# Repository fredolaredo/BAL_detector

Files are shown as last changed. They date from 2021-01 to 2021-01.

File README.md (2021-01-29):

# BAL_detector

## objectif

recevoir une notification sur ouverture de la boite aux lettre qui se trouve en bas de l'immeuble

fixation par aimant (je ne voulais pas faire de trous dans la BAL et plus facile pour récupérer pour recharger la batterie

basse consommation pour tourner avec une batterie sur plusieurs mois 

## principe

1. ouverture de la porte de la BAL par capteur magnétique

2. envoi d'un packet lora contenant des données ambiantes et le voltage de la batterie

3. notification IFTTT sur message TTN

## composants

atmega328 package DIP28 en 3,3V / 8Mhz

LoRa 1276

DHT22 (pour le fun)

une baterie Lithium 3,7v 1000mAh

un contacteur par effet magnétique

quelques composants passifs : led , resistances, capa de découplage, un push button, ...

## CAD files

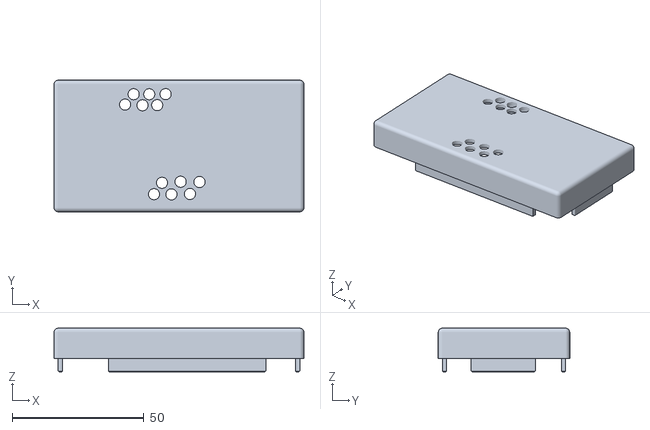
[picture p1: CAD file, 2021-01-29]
3D/BAL_haut.stl
95.0 x 50.0 x 16.6

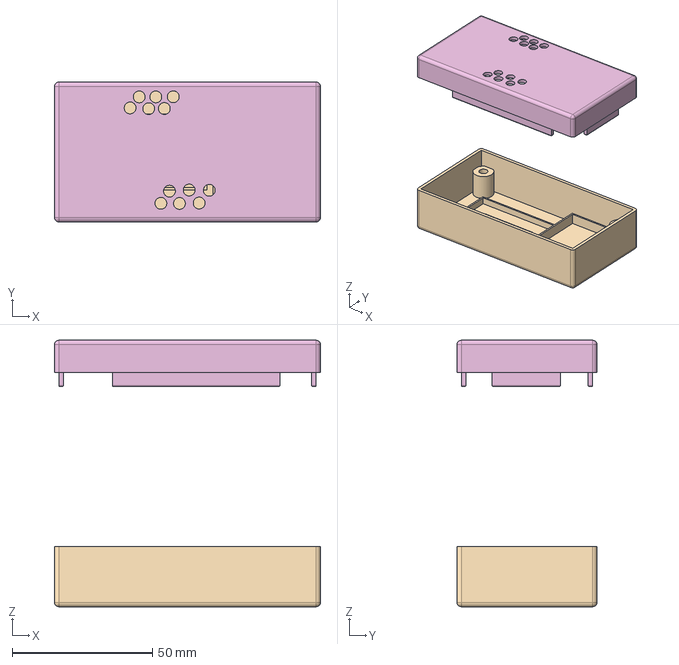
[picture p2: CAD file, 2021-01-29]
3D/boite.FCStd
95.0 x 50.0 x 95.2 mm
Bas
Couvercle

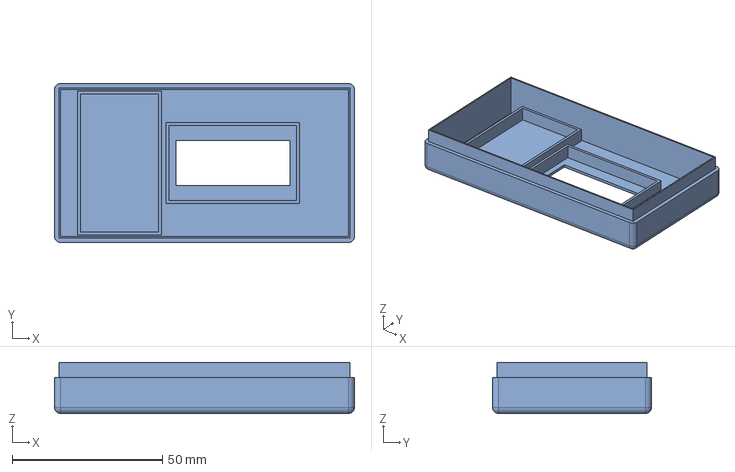
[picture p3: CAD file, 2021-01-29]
3D/coffre_91x47.FCStd
100.0 x 53.0 x 17.0 mm

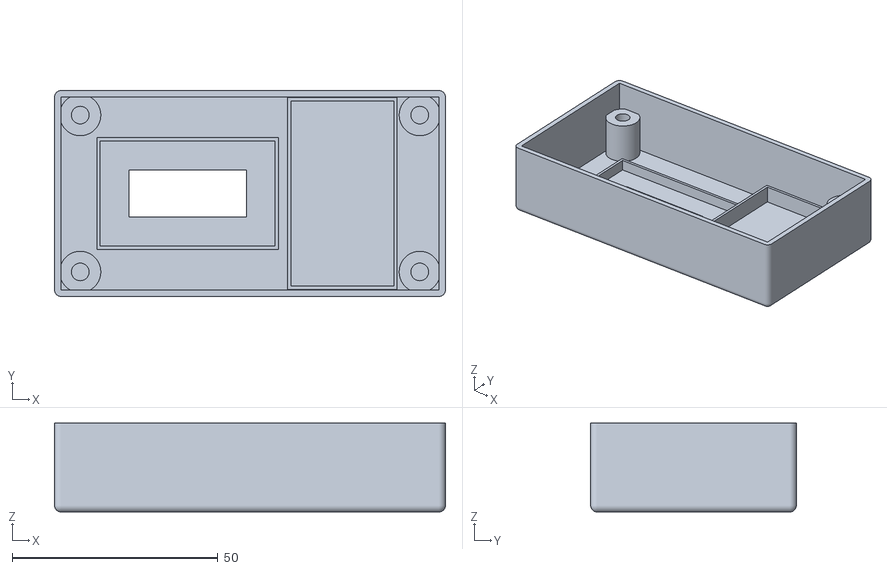
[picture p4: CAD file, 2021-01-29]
3D/BAL_bas.stl
95.0 x 50.0 x 21.6

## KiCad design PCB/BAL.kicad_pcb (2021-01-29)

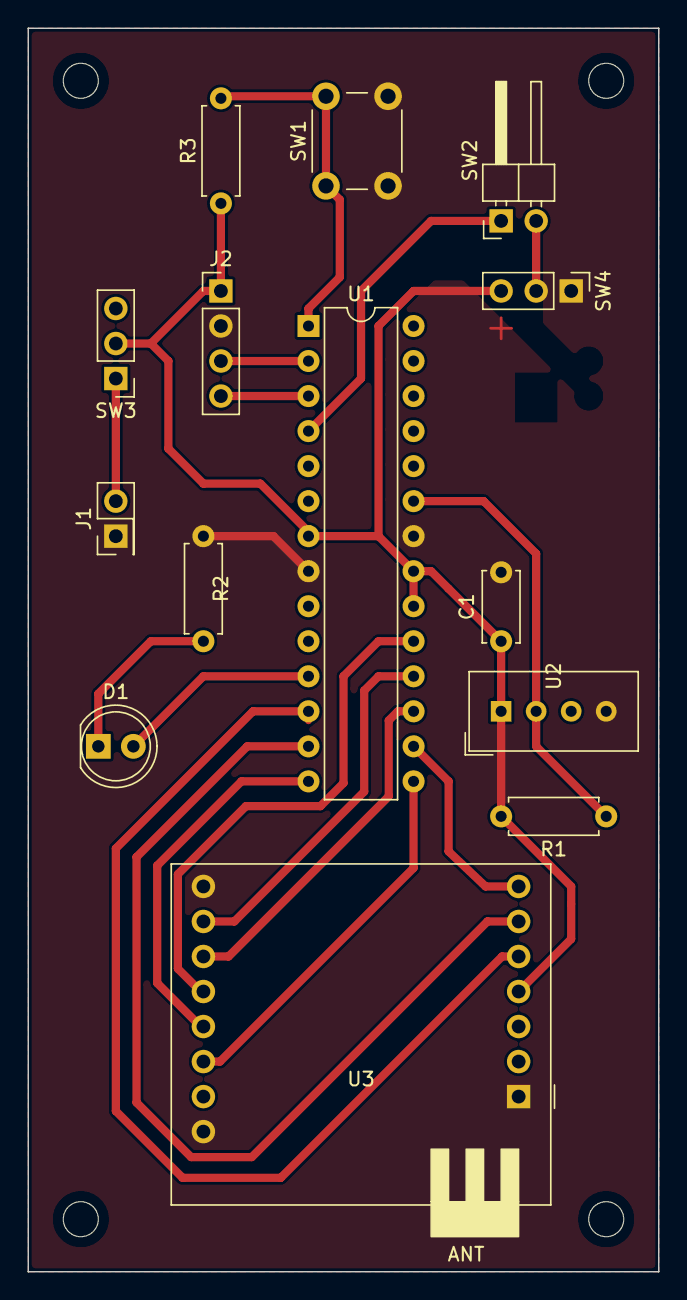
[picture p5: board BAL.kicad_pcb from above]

Board: 2 copper layers, 45.7 x 90.2 mm, 14 parts (0 on the bottom side), 19 nets.

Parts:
C1: 1nF; C_Disc_D5.0mm_W2.5mm_P5.00mm
D1: LED; LED_D5.0mm
J1: Battery; PinHeader_2x01_P2.54mm_Vertical
J2: UART; PinHeader_1x04_P2.54mm_Vertical
R1, R3: 10k; R_Axial_DIN0207_L6.3mm_D2.5mm_P7.62mm_Horizontal
R2: 180; R_Axial_DIN0207_L6.3mm_D2.5mm_P7.62mm_Horizontal
SW1: SW_Push; SW_PUSH_6mm
SW2: Detecteur; PinHeader_1x02_P2.54mm_Horizontal
SW3: SW_SPST; PinHeader_1x03_P2.54mm_Vertical
SW4: NO/NC; PinHeader_1x03_P2.54mm_Vertical
U1: ATmega328P-PU; DIP-28_W7.62mm
U2: DHT11; Aosong_DHT11_5.5x12.0_P2.54mm
U3: SX1276_package; SX1276_Package

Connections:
+3V3: C1.1, J2.1, R1.2, R3.1, SW3.2, SW4.3, U1.7, U1.20, U1.21, U2.1, U3.4
D0: U1.12, U3.5
D1: U1.13, U3.6
D2: U1.16, U3.7
DATA: R1.1, U1.23, U2.2
GND: C1.2, J1.1, J2.2, R2.1, SW1.2, SW4.1, U1.8, U1.22, U2.4, U3.1, U3.8, U3.15
MISO: U1.18, U3.14
MOSI: U1.17, U3.13
unnamed: D1.1, R2.2
unnamed: D1.2, U1.11
unnamed: J1.2, SW3.1
unnamed: R3.2, SW1.1, U1.1
unnamed: SW2.1, U1.4
unnamed: SW2.2, SW4.2
RST: U1.15, U3.10
RX: J2.4, U1.3
SCK: U1.19, U3.12
SS: U1.14, U3.11
TX: J2.3, U1.2

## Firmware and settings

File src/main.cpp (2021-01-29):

#include <Arduino.h>
#include "private.h"

#include <lmic.h>
#include <hal/hal.h>
#include <SPI.h>
#include "time.h"

#define CONTACT_PIN   2
#define LED_PIN       5
#define STANDARD_DIM  50

int nbLoop = 0;

enum STATE {
  INIT,
  SEND,
  WAIT_SEND,
  SLEEP,
  ERROR
};

volatile STATE state = INIT;

void dimLed(int msecs = 1000, int power = STANDARD_DIM, int num = 1) {
  #define pas 2
  for (int nb=0 ; nb < num ; nb++) {
    for (int j=0; j<power ; j+= pas ) {
      analogWrite(LED_PIN,j); 
      delay(msecs / 2 / (power / pas)); 
    }
    for (int j=power; j>0 ; j-= pas) {
      analogWrite(LED_PIN,j);  
      delay( msecs / 2 / (power / pas));
    }
    digitalWrite(LED_PIN,LOW);
  }
  
}


///////////////////////////////////////////////////////////////////
// DHT22
///////////////////////////////////////////////////////////////////
#include <Adafruit_Sensor.h>
#include <DHT.h>
#include <DHT_U.h>

#define DHTPIN     A0        // Digital pin connected to the DHT sensor 
#define DHTTYPE    DHT22     // DHT 22 (AM2302)

DHT_Unified dht(DHTPIN, 22);

uint32_t delayMS;
float temperature;
float humidity;

void initDHT() {
  Serial.println("DHT22 started");
  dht.begin();
}

void getTempHumid() {
  sensors_event_t event;

  dht.temperature().getEvent(&event);
  dht.humidity().getEvent(&event);
  
  dht.temperature().getEvent(&event);
  if (isnan(event.temperature)) {
    Serial.println(F("Error reading temperature!"));
  } else {
    Serial.print(F("Temperature: "));
    Serial.print(event.temperature);
    Serial.println(F("°C"));
    temperature = event.temperature;
  }
  dht.humidity().getEvent(&event);
  if (isnan(event.relative_humidity)) {
    Serial.println(F("Error reading humidity!"));
  } else {
    Serial.print(F("Humidity: "));
    Serial.print(event.relative_humidity);
    Serial.println(F("%"));
    humidity = event.relative_humidity;
  }
}

//////////////////////////////////////////////////////////////////
// SX1276
///////////////////////////////////////////////////////////////////

#define SX1276_NSS  8
#define SX1276_RST  9 
#define SX1276_DIO2 10
#define SX1276_MOSI 11
#define SX1276_MISO 12
#define SX1276_SCK  13
#define SX1276_DIO0 6
#define SX1276_DIO1 7

void opmode_str(){
  if (LMIC.opmode & OP_NONE) Serial.print(" OP_NONE");
  if (LMIC.opmode & OP_SCAN) Serial.print(" OP_SCAN");          // radio scan to find a beacon
  if (LMIC.opmode & OP_TRACK) Serial.print(" OP_TRACK");        // track my networks beacon (netid)
  if (LMIC.opmode & OP_JOINING) Serial.print(" OP_JOINING");    // device joining in progress (blocks other activities)
  if (LMIC.opmode & OP_TXDATA) Serial.print(" OP_TXDATA");      // TX user data (buffered in pendTxData)
  if (LMIC.opmode & OP_POLL) Serial.print(" OP_POLL");          // send empty UP frame to ACK confirmed DN/fetch more DN data
  if (LMIC.opmode & OP_REJOIN) Serial.print(" OP_REJOIN");      // occasionally send JOIN REQUEST
  if (LMIC.opmode & OP_SHUTDOWN) Serial.print(" OP_SHUTDOWN");  // prevent MAC from doing anything
  if (LMIC.opmode & OP_TXRXPEND) Serial.print(" OP_TXRXPEND");  // TX/RX transaction pending
  if (LMIC.opmode & OP_RNDTX) Serial.print(" OP_RNDTX");        // prevent TX lining up after a beacon
  if (LMIC.opmode & OP_PINGINI) Serial.print(" OP_PINGINI");    // pingable is initialized and scheduling active
  if (LMIC.opmode & OP_PINGABLE) Serial.print(" OP_PINGABLE");  // we're pingable
  if (LMIC.opmode & OP_NEXTCHNL) Serial.print(" OP_NEXTCHNL");  // find a new channel
  if (LMIC.opmode & OP_LINKDEAD) Serial.print(" OP_LINKDEAD");  // link was reported as dead
  if (LMIC.opmode & OP_TESTMODE) Serial.print(" OP_TESTMODE");  // developer test mode
}


#ifdef ABP
  uint8_t APPSKEY[16] = SECRET_APPKEY;  
  uint8_t NWKSKEY[16] = SECRET_NWKSKEY;   
  static const u4_t DEVADDR =  SECRET_DEVADDR; 
  void os_getArtEui (u1_t* buf) { }
  void os_getDevEui (u1_t* buf) { }
  void os_getDevKey (u1_t* buf) { }
#else
  static const u1_t PROGMEM APPEUI[8]= SECRET_APPEUI;
  void os_getArtEui (u1_t* buf) { memcpy_P(buf, APPEUI, 8);}
  static const u1_t PROGMEM DEVEUI[8]= SECRET_DEVEUI;
  void os_getDevEui (u1_t* buf) { memcpy_P(buf, DEVEUI, 8);}
  static const u1_t PROGMEM APPKEY[16] = SECRET_APPKEY;
  void os_getDevKey (u1_t* buf) {  memcpy_P(buf, APPKEY, 16);}
#endif

static uint8_t mydata[] = "device3";
static osjob_t sendjob;

// Pin mapping
const lmic_pinmap lmic_pins = {
    .nss = SX1276_NSS,
    .rxtx = LMIC_UNUSED_PIN,
    .rst = SX1276_RST,
    .dio = {SX1276_DIO0,SX1276_DIO1,SX1276_DIO2}
};

void onEvent (ev_t ev) {
    Serial.println();

    const uint32_t gt = os_getTime();
    tm *mytl = localtime(&gt);
    Serial.print(mytl->tm_hour); Serial.print(":"); Serial.print(mytl->tm_min); Serial.print(":");Serial.print(mytl->tm_sec); 

    Serial.print(String(" - ") + ev + String(" : "));
    switch(ev) {
        case EV_SCAN_TIMEOUT:
            Serial.println(F("EV_SCAN_TIMEOUT"));
            break;
        case EV_JOINING:
            Serial.println(F("EV_JOINING"));
            break;
        case EV_JOINED:
            Serial.println(F("EV_JOINED"));
            LMIC_setLinkCheckMode(0);
            break;
        case EV_JOIN_FAILED:
            Serial.println(F("EV_JOIN_FAILED"));
            break;
        case EV_REJOIN_FAILED:
            Serial.println(F("EV_REJOIN_FAILED"));
            break;
        case EV_TXCOMPLETE:
            Serial.println(F("EV_TXCOMPLETE (includes waiting for RX windows)")); 
            if (LMIC.txrxFlags & TXRX_ACK)
              Serial.println(F("Received ack"));
            if (LMIC.dataLen) {
              Serial.println(F("Received "));
              Serial.println(LMIC.dataLen);
              Serial.println(F(" bytes of payload"));
            }
            state = SLEEP;
            break;
        case EV_LOST_TSYNC:
            Serial.println(F("EV_LOST_TSYNC"));
            break;
        case EV_RESET:
            Serial.println(F("EV_RESET"));
            break;
        case EV_RXCOMPLETE:
            // data received in ping slot
            Serial.println(F("EV_RXCOMPLETE"));
            break;
        case EV_LINK_DEAD:
            Serial.println(F("EV_LINK_DEAD"));
            break;
        case EV_LINK_ALIVE:
            Serial.println(F("EV_LINK_ALIVE"));
            break;
         default:
            Serial.println(F("Unhandled event : "));
            break;
    }
}

void do_send(osjob_t* j){
    // Check if there is not a current TX/RX job running
    if (LMIC.opmode & OP_TXRXPEND) {
        Serial.println(F("OP_TXRXPEND, not sending"));
    } else {
        // Prepare upstream data transmission at the next possible time.
        LMIC_setTxData2(1, mydata, sizeof(mydata)-1, 0);
        Serial.println(F("Packet queued"));
    }
    // Next TX is scheduled after TX_COMPLETE event.
}

void do_send_array(osjob_t* j, xref2u1_t data, int size){
    // Check if there is not a current TX/RX job running
    if (LMIC.opmode & OP_TXRXPEND) {
        Serial.println(F("OP_TXRXPEND, not sending"));
    } else {
        // Prepare upstream data transmission at the next possible time.
        LMIC_setTxData2(1, data, size, 0);
        Serial.println(F("Packet queued"));
    }
    // Next TX is scheduled after TX_COMPLETE event.
}

void init_lmic() {
    // LMIC init
    os_init();
    // Reset the MAC state. Session and pending data transfers will be discarded.
    LMIC_reset();
    #ifdef ABP
      LMIC_setSession (0x1, DEVADDR, NWKSKEY, APPSKEY);
      //LMIC_setupChannel(0, 868100000, DR_RANGE_MAP(DR_SF12, DR_SF7),  BAND_CENTI);      // g-band
      // LMIC_setupChannel(0, 868100000, DR_RANGE_MAP(DR_SF7,DR_SF12),  BAND_CENTI);      // g-band
      // LMIC_setupChannel(0, 868100000, DR_SF7,  BAND_CENTI);      // g-band
      for (int i=1 ; i < 9 ; i++) LMIC_disableChannel(i);
      LMIC_setDrTxpow(DR_SF7,14);
      // Disable link check validation
      LMIC_setLinkCheckMode(0);
      // TTN uses SF9 for its RX2 window.
      LMIC.dn2Dr = DR_SF9;
      // Set data rate and transmit power for uplink (note: txpow seems to be ignored by the library)
    #else
      LMIC_setClockError(MAX_CLOCK_ERROR * 1 / 100);
    #endif
    
    
}

///////////////////////////////////////////////////////////////////

ISR(WDT_vect){
  //DON'T FORGET THIS!  Needed for the watch dog timer.  
  //This is called after a watch dog timer timeout - 
  //this is the interrupt function called after waking up
}// watchdog interrupt

void digitalInterrupt(){
  //needed for the digital input interrupt
  //Serial.println("interrupt !");
  if (state == SEND || state == WAIT_SEND) {
    //Serial.println("already in SEND process");
  } else {
    state = SEND;
  //do_send(&sendjob);
  }
}

void setup_sleep_mode() {
  //ENABLE SLEEP - this enables the sleep mode
  SMCR |= (1 << 2); //power down mode
  SMCR |= 1;//enable sleep

  //SETUP WATCHDOG TIMER
  //WDTCSR = (24);//change enable and WDE - also resets
  //WDTCSR = (33);//prescalers only - get rid of the WDE and WDCE bit
  //WDTCSR |= (1<<6);//enable interrupt mode
}

void goToSleep() {
  // Disable ADC - don't forget to flip back after waking up if using ADC in your application ADCSRA |= (1 << 7);
  ADCSRA &= ~(1 << 7);

  MCUCR |= (3 << 5); //set both BODS and BODSE at the same time
  MCUCR = (MCUCR & ~(1 << 5)) | (1 << 6); //then set the BODS bit and clear the BODSE bit at the same time
  __asm__  __volatile__("sleep");//in line assembler to go to sleep
}

///////////////////////////////////////////////////////////////////

long int readVcc() {
  // Read 1.1V reference against AVcc
  // set the reference to Vcc and the measurement to the internal 1.1V reference
  #if defined(__AVR_ATmega32U4__) || defined(__AVR_ATmega1280__) || defined(__AVR_ATmega2560__)
    ADMUX = _BV(REFS0) | _BV(MUX4) | _BV(MUX3) | _BV(MUX2) | _BV(MUX1);
  #elif defined (__AVR_ATtiny24__) || defined(__AVR_ATtiny44__) || defined(__AVR_ATtiny84__)
    ADMUX = _BV(MUX5) | _BV(MUX0);
  #elif defined (__AVR_ATtiny25__) || defined(__AVR_ATtiny45__) || defined(__AVR_ATtiny85__)
    ADMUX = _BV(MUX3) | _BV(MUX2);
  #else
    ADMUX = _BV(REFS0) | _BV(MUX3) | _BV(MUX2) | _BV(MUX1);
  #endif  

  delay(2); // Wait for Vref to settle
  ADCSRA |= _BV(ADSC); // Start conversion
  while (bit_is_set(ADCSRA,ADSC)); // measuring

  uint8_t low  = ADCL; // must read ADCL first - it then locks ADCH  
  uint8_t high = ADCH; // unlocks both

  long int result = (high<<8) | low;

  result = 1125300L / result; // Calculate Vcc (in mV); 1125300 = 1.1*1023*1000
  return result; // Vcc in millivolts
}

long int Vint = 0;

///////////////////////////////////////////////////////////////////

void setup() {
  Serial.begin(115200);
  delay(50);
  Serial.println("----> Setup");
  dimLed(1000);
  // for low power : to be tested
  for (int i = 0; i < 20; i++) {
    pinMode(i, INPUT);
  }
  pinMode(CONTACT_PIN,INPUT);
  pinMode(LED_PIN, OUTPUT);
  digitalWrite(LED_PIN, LOW);
  Serial.println("attachInterrupt " + String(CONTACT_PIN));
  attachInterrupt(digitalPinToInterrupt(CONTACT_PIN), digitalInterrupt,RISING);
  init_lmic();
  setup_sleep_mode();
  initDHT();
  getTempHumid();
  Serial.println("----> Setup Ended");
  dimLed(1000);
}

///////////////////////////////////////////////////////////////////

void loop() {
  //Serial.println("----> Loop : " + String(nbLoop++));

  switch (state) {
  case INIT:
    Serial.println("---- INIT ----"); delay(100);
    opmode_str(); Serial.println();
    state = SLEEP;
    break;

  case SEND:
    Serial.println("---- SEND ----"); //delay(100);
    dimLed(100);
    // opmode_str(); Serial.println();
    Serial.print("LMIC Batt Level : "); Serial.print( map(os_getBattLevel(),0,255,0,100)); Serial.println("%");
    Vint = readVcc();
    Serial.print("battery : "); Serial.print(Vint); Serial.println("mV");
    getTempHumid();
    u1_t payload[7];
    payload[0] = Vint >> 8; 
    payload[1] = Vint & 0xFF;
    payload[2] = (int)(temperature*100) >> 8;
    payload[3] = (int)(temperature*100) & 0xFF;
    payload[4] = (int)(humidity*100) >> 8;
    payload[5] = (int)(humidity*100) & 0xFF;
    payload[6] = DEVICE_ID;
    do_send_array(&sendjob, payload, 7);
    opmode_str(); Serial.println();
    state = WAIT_SEND;
    break;

  case WAIT_SEND:
    // Serial.print("---- WAIT_SEND ---- "); 
    os_runloop_once();
    // if (LMIC.opmode & OP_TXRXPEND) {
    //   Serial.print("sending... ");
    // }
    //Serial.print("Op mode = "); Serial.print(LMIC.opmode); Serial.print("                                     \r");
    // opmode_str(); Serial.print("\n\r"); 
    break;

  case SLEEP:
    Serial.println("---- SLEEP ----"); delay(100);
    // hal_sleep(); not implemented
    // os_radio(RADIO_RST); // SX1276 into Sleep Mode
    // LMIC_init();
    // init_lmic();
    // sensor_t sensor;
    // dht.temperature().getSensor(&sensor);
    dimLed(2000);
    Serial.flush();
    goToSleep(); 
    ADCSRA |= (1 << 7);
    break;

  case ERROR:
    state = SLEEP;
    break;

  default:
    Serial.println("---- UNKNOWN ----"); delay(100);
    dimLed(100);
    Serial.flush();
    state = SLEEP;
    break;
  }
  
  //Serial.println("wait few secs .....");
  delay(100);
}


///////////////////////////////////////////////////////////////////
